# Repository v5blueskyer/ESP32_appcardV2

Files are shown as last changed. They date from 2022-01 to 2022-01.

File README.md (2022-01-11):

# appcardV2
基于乐鑫esp32的多功能应用卡片V2，天气时钟投屏等全都有，QQ技术群：801516857

原理图及PCB见立创开源社区：https://oshwhub.com/blueskyer/appcardv2

20220101更新，
 //我的更改说明：V1.2程序，修改了烧录方式，不再需要使用麻烦的arduino分区了，直接一键烧写。
烧写见附件说明

20211209更新，增加了闹钟固件，具体见附件里面txt

 //我的更改说明：V1.1程序

//1,增加了闹钟,在配网里面，配网完成后需要上电前按下按键选择闹钟打开模式才能使用,默认响1分钟,响铃的时候长按按键可关闭。

注意烧写bin文件前，必须用arduino刷个空程序以便将分区信息刷进去后才能操作刷bin程序，这点esp32和esp8266完全不一样。

一，    硬件部分
1，pcb板打板使用“Gerber_PCB_appcardV2.zip”，也可，直接打板即可。
板子厚度1.6mm，无其他要求，因为3d外壳是根据这个设计的

2，元器件采购
直接按照原理图或者pcb图。

蜂鸣器高度需要注意，3d外壳预留了1.5mm，实际最终
蜂鸣器高度不能超过5.5mm。

另外使用的是esp32 wrover，不是wroom，二者封装不同。

3，    其他硬件材料
（1）    屏幕

插接款-不带触屏，st7789

需要触屏的自己开发，电路和程序需要修改的

（2）    螺丝
螺丝使用4个m2*10或者8个m1*5的，担心滑丝的，尽量买m1的螺丝

4，3d打印外壳

文件有4个，但是类型有3个

appcard-Body是底壳
appcard-Body001是盖板
appcard-btn002和appcard-btn003对应不同长度的按键，前面一个安装后多出来1mm，后面一个多出来2mm

3d打印方式尽量选择光固化，因为那几个1mm螺丝孔要求精度高，其他打印方式可能不够好。

5，焊接和装配说明
  焊接和装配可看b站视频
  焊接需要注意的有
A，插件引脚需要剪掉和pcb持平
B，光敏电阻是需要多出来一点，刚好在开槽那里弯折一下，然后伸出来一部分
 
C，Typec固定的4个脚尽量往外移动一些，这样方便typec座子里面的卡子卡住typec数据线
D，pcb的挨在一起的B和G是用于短接用的，可以不焊接插针。
   6个排针那里不用串口的话可以不焊接，需要用只焊接4个（3V3，G，RX，TX）就行，不论是插针还是排母都需要弯折一下
不然高度太高了，根本安装不上外壳了

 6，5v的typec供电部分电源，尽量选择低电流的充电器，1a或者2a的，不要使用太大电流的。

更多内容参看附件里面的PDF文档，附件限制了文件大小，彩屏投屏助手太大我放到网盘了。

网盘链接：https://pan.baidu.com/share/init?surl=oSA9dAb9utCoeQdWQqr4jA

提取码：9527

高清视频请查看：https://www.bilibili.com/video/BV1wg411w77z/

欢迎点赞和收藏

<br>我的更改说明：V1.0程序
<br>移植SD2代码到esp32，引脚需改变，引脚和分辨率需改变，主要更改Arduino\libraries\TFT_eSPI\User_Setup.h以及主程序appcard.ino中窗口大小
<br>底部空区域增加b站粉丝数，增加用于显示b站字符的中文字体，底部增加b站图标
<br>增加NVS读取，esp32和8266的wifi用户名和密码保存区不一样，8266直接保存在flash区不用额外处理，esp32保存在NVS区需要手动调用
<br>修改配网模式，改为web配网，配网页面中可输入城市代码和b站uid
<br>城市名称字体不全，替换全量字体
<br>增加自动亮度控制
<br>增加开机动画，目前3张，需要其他图片自行修改后编译
<br>预留闹钟功能，后续添加代码
<br>修改串口功能，去掉了城市代码设置(因为配网中已经有了)，新增常用亮度设置（自动亮度关闭时），最低亮度设置（自动亮度打开时），英语单词本轮播时间设置(分钟)
<br>断电情况下，按下按钮不松开，然后插上TYPE-C数据线通电，上电后大概等待1秒，屏幕上会有提示，提示停留在哪一个步骤，松开按钮就会进入该步骤，重启后生效
<br>按键控制功能有：
<br>1,自动亮度打开与关闭
<br>2,配网模式
<br>3,开机动画关闭
<br>4,开机动画设置为图片1（默认）
<br>5,开机动画设置为图片2
<br>6,开机动画设置为图片3
<br>7,底部动画设置为图片1（默认）
<br>8,底部动画设置为图片2
<br>9,页面选择1天气时钟（默认）
<br>10,页面选择2全屏数字时钟
<br>11,页面选择3圆盘时钟
<br>12,页面选择4投屏助手
<br>13,页面选择5英语单词本
<br>14,页面选择6喝水小助手
<br>15,页面选择7游戏flappy bird
<br>16,页面选择8系统信息
<br>17,页面选择9关于
<br>增加全屏数字时钟界面，按下按键可立即同步ntp时间
<br>增加圆盘时钟界面，按下按键可立即同步ntp时间
<br>增加投屏功能页面，需上位机配合
<br>增加英语单词本功能，支持轮播时间设置，按下按键可立即换单词和同步ntp时间,默认7990个单词。
<br>增加喝水小助手功能，默认8杯水，按一次增加一次，提示不同内容和显示进度，掉电不丢失，每天夜间1点10分清0重新计数。超过24次后，重启会清零。
<br>增加游戏flappy bird，按键操作，最高分保存记录掉电不丢失

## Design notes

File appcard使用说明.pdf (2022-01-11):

Appcard 使用说明

# 一， 硬件部分

1， pcb 板打板使用“Gerber_PCB_appcardV2.zip”，直接打板即可。 板子厚度 1.6mm，无其他要求，因为 3d 外壳是根据这个设计的

2， 元器件采购
直接按照原理图或者 pcb 图。
立创开源地址： https://oshwhub.com/blueskyer/appcardv2

蜂鸣器高度需要注意，3d 外壳预留了 1.5mm，实际最终 蜂鸣器高度不能超过 5.5mm。

另外使用的是 esp32 wrover，不是 wroom，二者封装不同。

3， 其他硬件材料
（1） 屏幕
https://item.taobao.com/item.htm?spm=a1z09.2.0.0.54c02e8dASAeNj&id=605985020631&_u=rpab1dmd2dc

插接款-不带触屏，23 元

需要触屏的自己开发，电路和程序需要修改的

（2） 螺丝
螺丝使用 4 个 m2*10 或者 8 个 m1*5 的，担心滑丝的，尽量买 m1 的螺丝

4，3d 打印外壳

文件有 4 个，但是类型有 3 个

appcard-Body 是底壳
appcard-Body001 是盖板
appcard-btn002 和 appcard-btn003 对应不同长度的按键，前面一个安装后多出来 1mm，后面一个多出来 2mm

3d 打印方式尽量选择光固化，因为那几个 1mm 螺丝孔要求精度高，其他打印方式可能不够好。

5，焊接和装配说明
焊接和装配可看 b 站视频
焊接需要注意的有
A，插件引脚需要剪掉和 pcb 持平
B，光敏电阻是需要多出来一点，刚好在开槽那里弯折一下，然后伸出来一部分

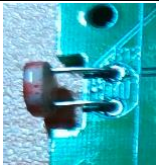
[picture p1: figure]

C， Typec 固定的 4 个脚尽量往外移动一些，这样方便 typec 座子里面的卡子卡住 typec 数据线
D，第一个框的 B 和 G 是用于短接用的，可以不焊接插针。 第二个框的，不用串口的话可以不焊接，需要用只焊接画框的 4 个就行，不论是插针还是排母都需要弯折一下 不然高度太高了，根本安装不上外壳了，类似下图处理。

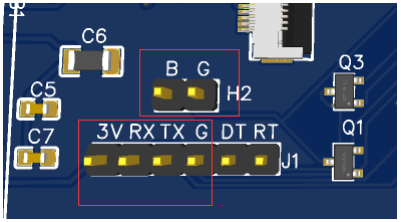
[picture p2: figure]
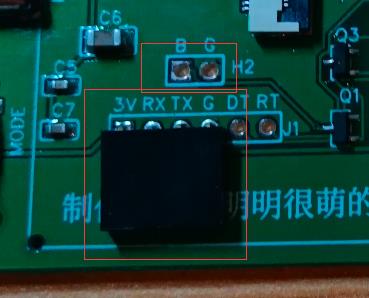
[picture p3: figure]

6，5v 的 typec 供电部分电源，尽量选择低电流的充电器，1a 或者 2a 的，不要使用太大电流的。

# 二， 软件部分

## 1， 程序烧录方法

板子自带 ch340c 下载器，同时预留了 usb 转 ttl 串口，可以上电前短接 boot 和 gnd，再接 usb 转 ttl 即可

图上最上面 2 个短接，下面 4 个用于 usb 转 ttl。

（1）所需软件，arduino，flash_download_tool，分区表相关文件(见分区表文件夹)

（2）Arduino 需要配置好开发板类型，开发板管理里面能够显示 esp32 wrover，教程这里就不罗列了，可以自行百 度。

（3）接着替换分区表文件，因为本程序是 3.5M，默认分区表最大只有 3M

涉及 2 个文件，操作前最好备份一下你自己的文件。

（4）替换 boards.txt，这个定义的是板子类型及指向的分区表文件名 C:\Users\你的用户名\AppData\Local\Arduino15\packages\esp32\hardware\esp32\1.0.6

（5）新增 big_app.csv，这个定义分区信息，不要去编辑，可以查看，csv 容易乱码保存容易出问题 C:\Users\你的用户名\AppData\Local\Arduino15\packages\esp32\hardware\esp32\1.0.6\tools\partitions

看不到隐藏文件夹请打开操作系统对应设置，自行百度，这里就不说了。

(6) arduino 新建一个空白程序，然后选择分区表，烧写进去，这一步是位了将分区信息写进去

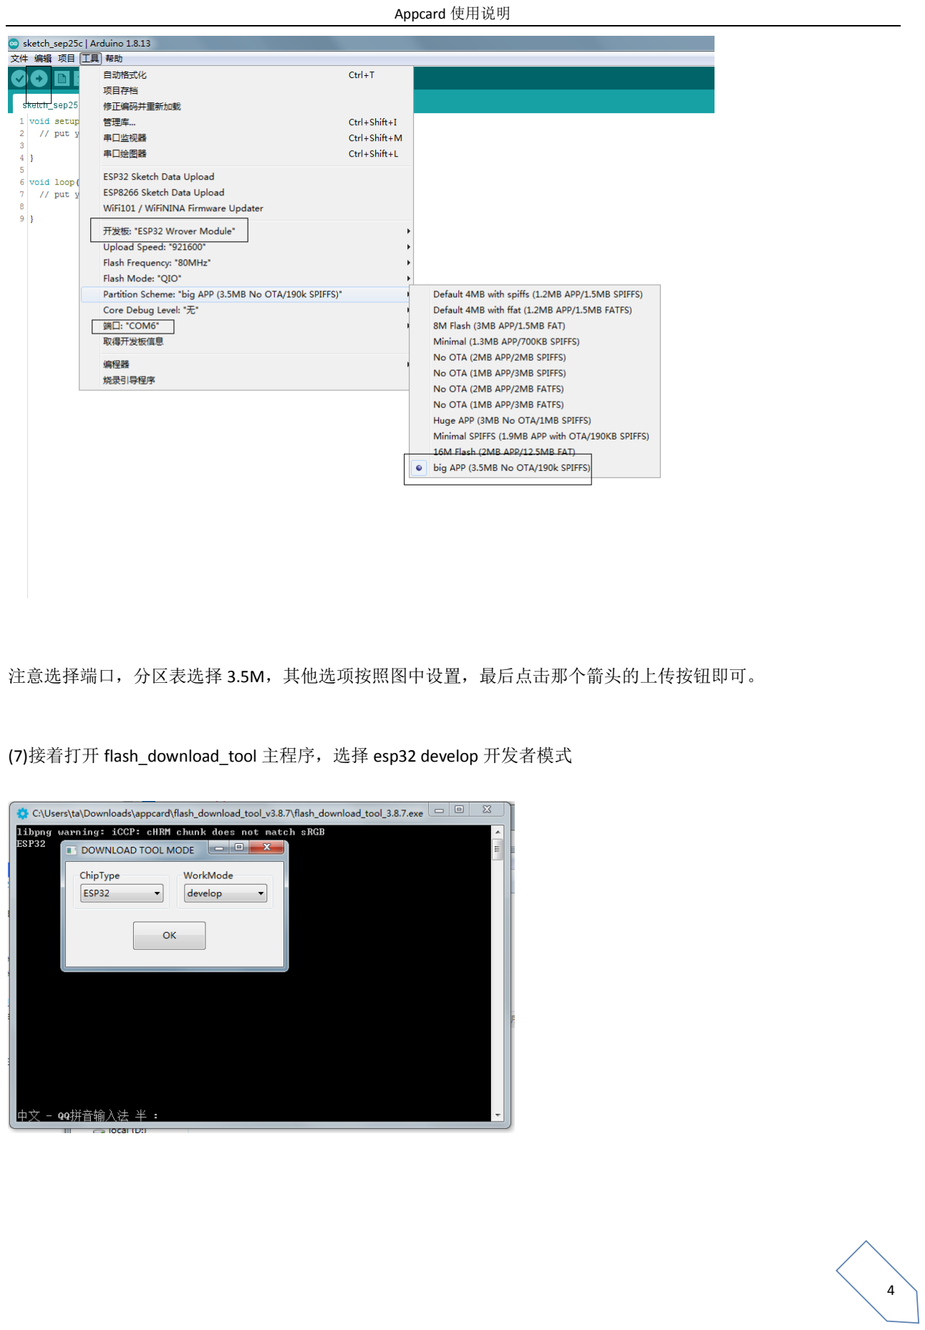
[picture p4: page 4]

注意选择端口，分区表选择 3.5M，其他选项按照图中设置，最后点击那个箭头的上传按钮即可。

(7)接着打开 flash_download_tool 主程序，选择 esp32 develop 开发者模式

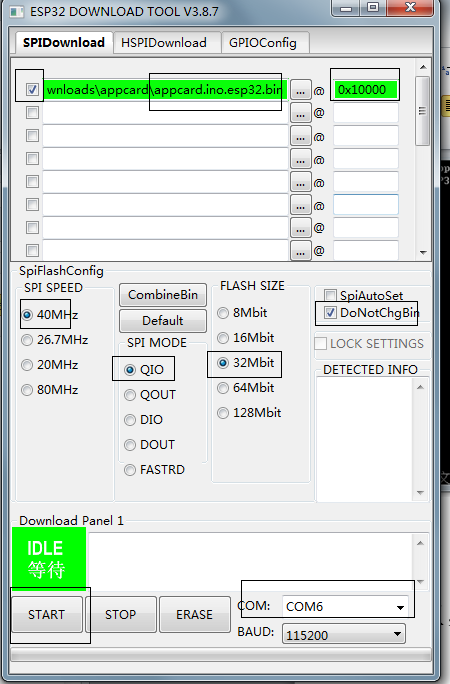
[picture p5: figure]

先选择固件 bin 文件，勾选，然后填入地址 0x10000，除了 com 口外其他按照图中设置即可，com 口根据你对应上 的，一般操作系统设备管理器端口里面可以看到

点击 start 就开始刷写了，刷写后需要拔电源重新插上屏幕才有显示。

到这里基本刷写就结束了，接下来是软件使用部分了。

## 2， 软件使用教程

（1） 先罗列我修改了哪些功能吧，后面也基本围绕这个。

//我的更改说明：V1.0 程序
//移植 SD2 代码到 esp32，引脚需改变，引脚和分辨率需改变，主要更改 Arduino\libraries\TFT_eSPI\User_Setup.h 以

及主程序 appcard.ino 中窗口大小
//底部空区域增加 b 站粉丝数，增加用于显示 b 站字符的中文字体，底部增加 b 站图标
//增加 NVS 读取，esp32 和 8266 的 wifi 用户名和密码保存区不一样，8266 直接保存在 flash 区不用额外处理，esp32 保存在 NVS 区需要手动调用
//修改配网模式，改为 web 配网，配网页面中可输入城市代码和 b 站 uid
//城市名称字体不全，替换全量字体
//增加自动亮度控制
//增加开机动画，目前 3 张，需要其他图片自行修改后编译
//预留闹钟功能，后续添加代码
//修改串口功能，去掉了城市代码设置(因为配网中已经有了)，新增常用亮度设置（自动亮度关闭时），最低亮度设 置（自动亮度打开时），英语单词本轮播时间设置(分钟)
//断电情况下，按下按钮不松开，然后插上 TYPE-C 数据线通电，上电后大概等待 1 秒，屏幕上会有提示，提示停留 在哪一个步骤，松开按钮就会进入该步骤，重启后生效
//按键控制功能有：
//1,自动亮度打开与关闭
//2,配网模式
//3,开机动画关闭
//4,开机动画设置为图片 1（默认）
//5,开机动画设置为图片 2
//6,开机动画设置为图片 3
//7,底部动画设置为图片 1（默认）
//8,底部动画设置为图片 2
//9,页面选择 1 天气时钟（默认）
//10,页面选择 2 全屏数字时钟
//11,页面选择 3 圆盘时钟
//12,页面选择 4 投屏助手
//13,页面选择 5 英语单词本
//14,页面选择 6 喝水小助手
//15,页面选择 7 游戏 flappy bird
//16,页面选择 8 系统信息
//17,页面选择 9 关于
//增加全屏数字时钟界面，按下按键可立即同步 ntp 时间
//增加圆盘时钟界面，按下按键可立即同步 ntp 时间
//增加投屏功能页面，需上位机配合
//增加英语单词本功能，支持轮播时间设置，按下按键可立即换单词和同步 ntp 时间,默认 7990 个单词。 //增加喝水小助手功能，默认 8 杯水，按一次增加一次，提示不同内容和显示进度，掉电不丢失，每天夜间 1 点 10 分清 0 重新计数。超过 24 次后，重启会清零。
//增加游戏 flappy bird，按键操作，最高分保存记录掉电不丢失
(2) 首次使用开机后会显示配网信息页面，用手机或者电脑找到名为“appcard”这个无线网进行连接，默认无密码的， 接着会弹一个浏览器弹窗，如果没弹窗则需要你打开浏览器手动输入”192.168.4.1”。

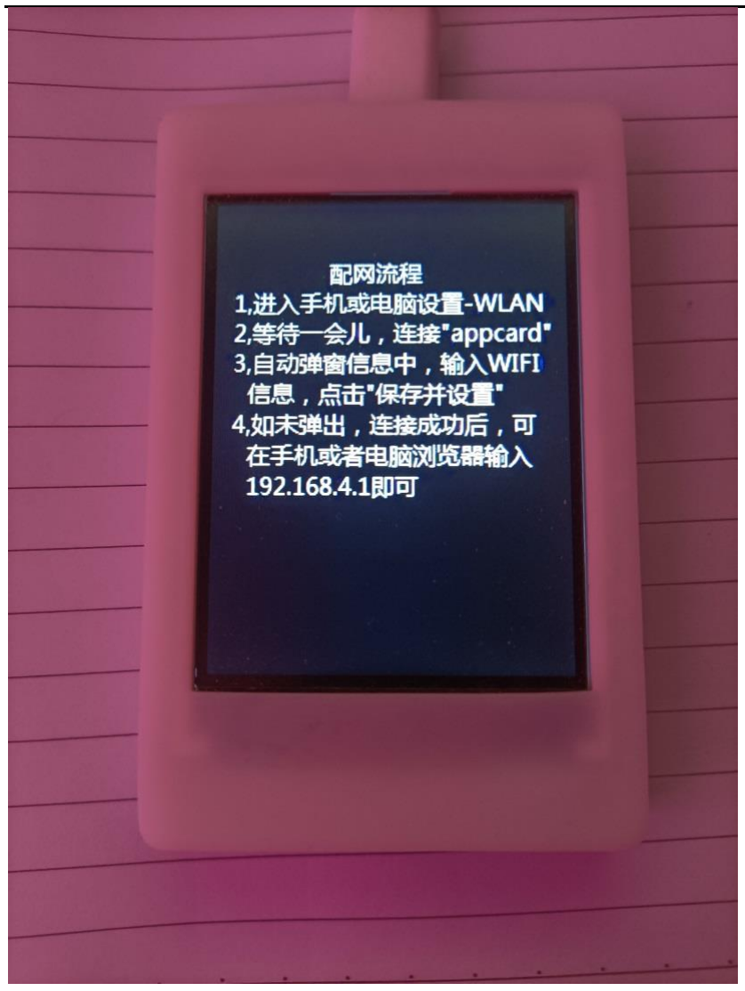
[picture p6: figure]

(3) 接着填入 wifi 网络名和密码即可，城市 id 和 b 站 id 也可以不填。 城市 id 是自动获取的，但有时候获取不准，所以建议还是填一下。 B 站 id 是默认 up 的 id，如果需要你自己的可以填一下。
城市 id，可以在 citycode 文件里面的 js 获取，本稳当结尾也会加的。

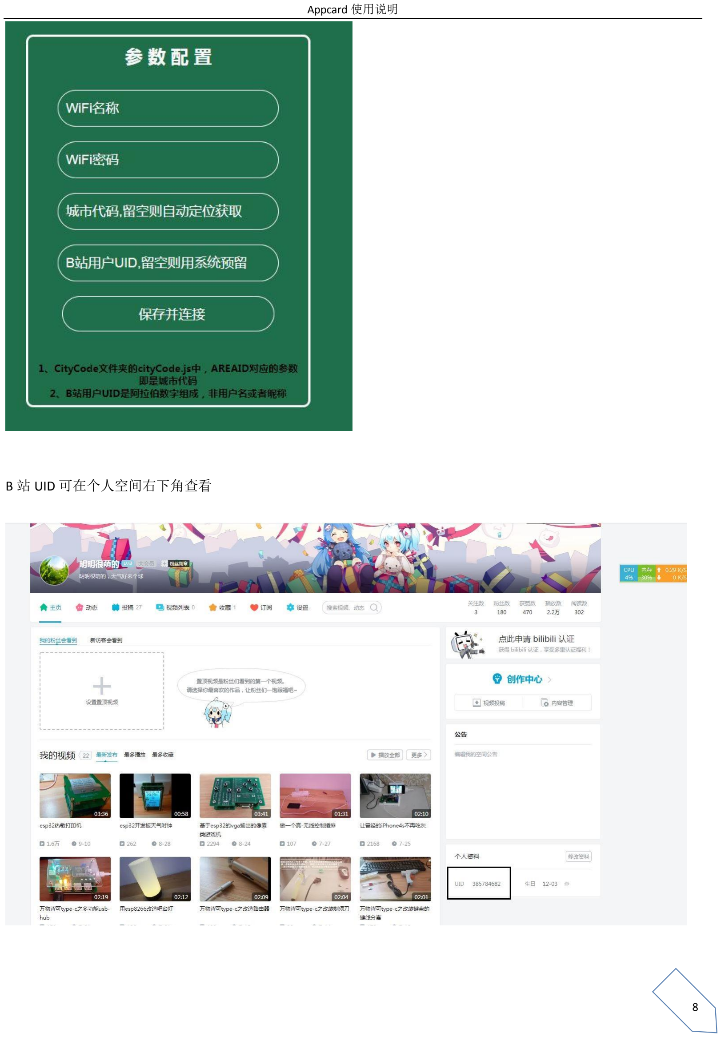
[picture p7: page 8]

B 站 UID 可在个人空间右下角查看

（4）默认首次进入天气时钟界面，进入时界面元素较多，有些卡，可以等待一下即可。 如果界面元素不全或者时间不对，可以重新上电进入即可，后续其他页面的时间不对也是如此操作。

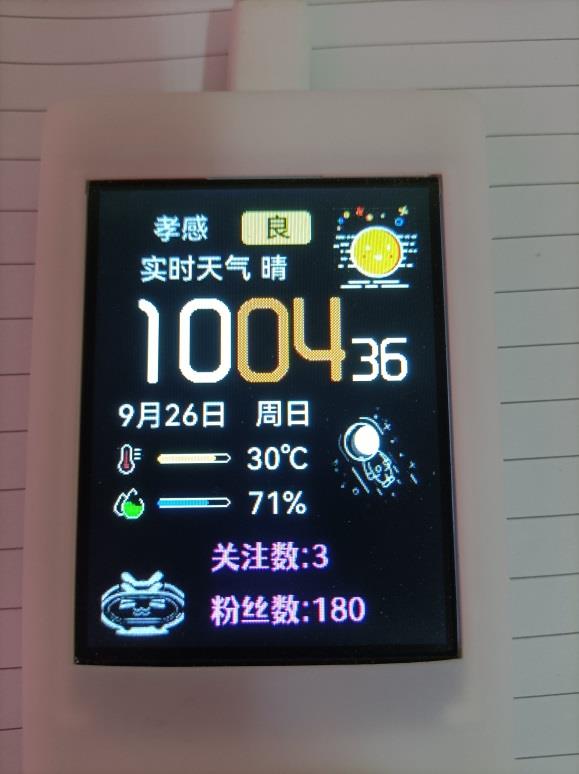
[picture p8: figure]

按下按键可以立即刷新时间和粉丝数

基本上到此，就可以正常使用了，后续讲其他功能。

（5）如果要调整显示页面和进行一些设置，可以用串口工具或者按键。

（6）先说下串口工具，不用网上下载各种串口软件，直接使用 arduino 的即可 打开 arduino 串口监视器，注意端口要正确

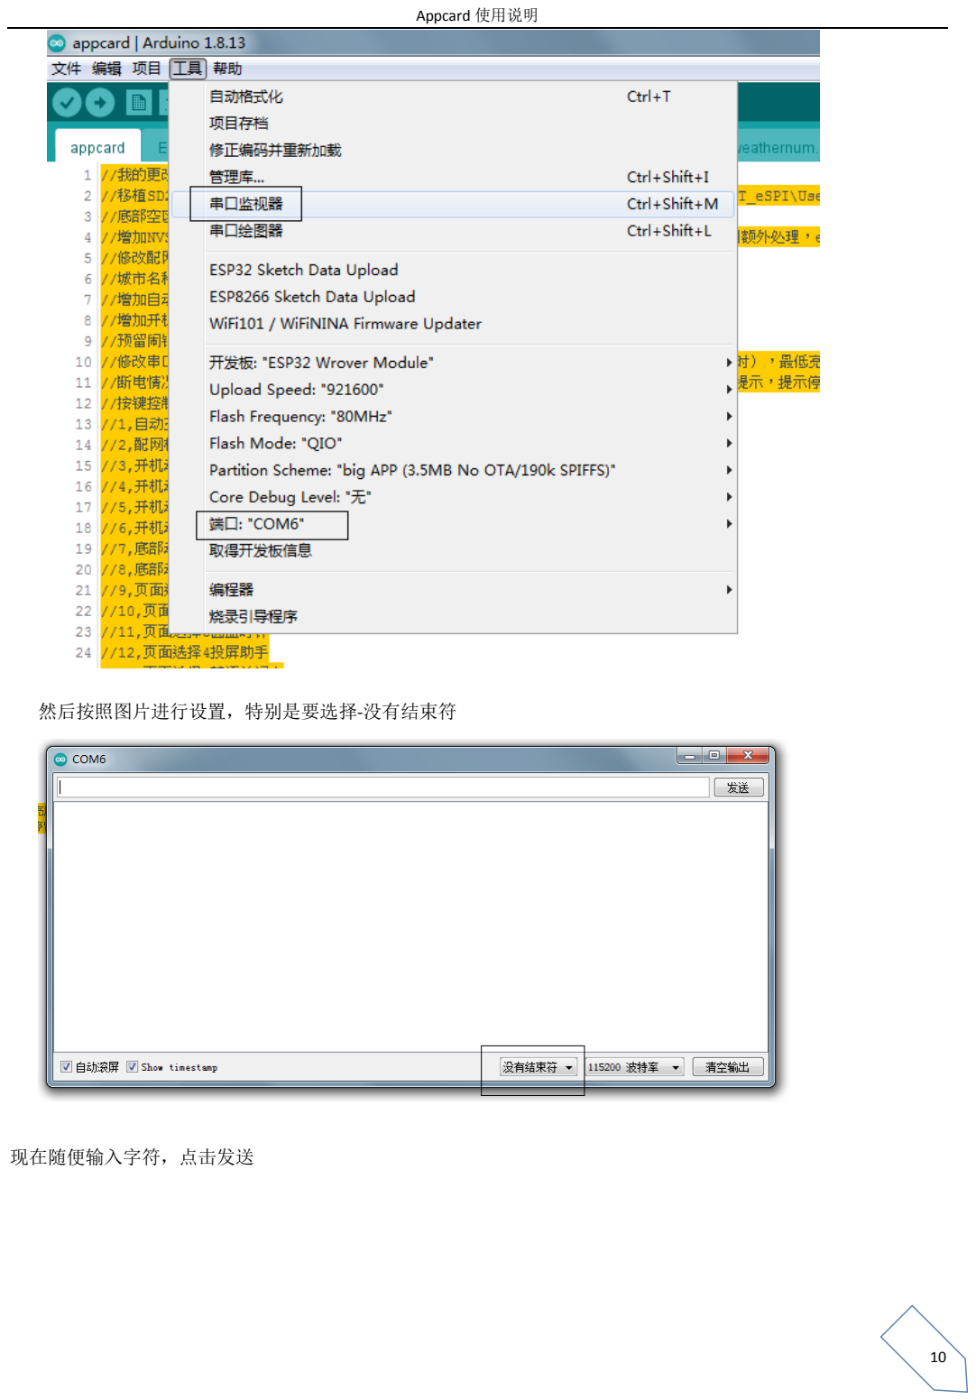
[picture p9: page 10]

然后按照图片进行设置，特别是要选择-没有结束符

现在随便输入字符，点击发送

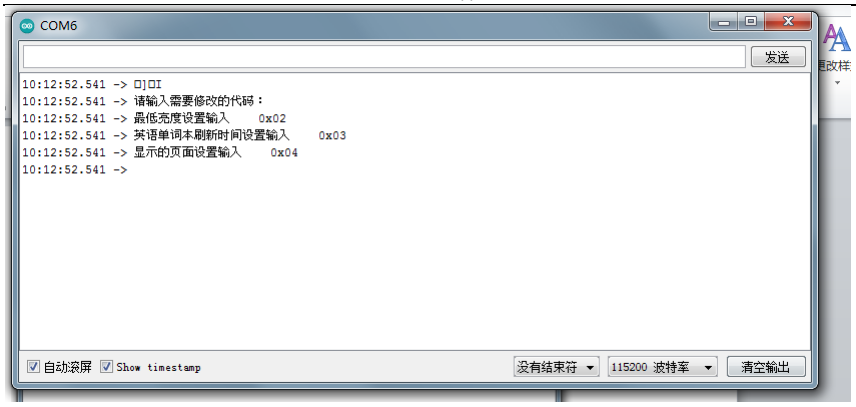
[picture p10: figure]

默认有 4 个设置
0x01 常用亮度设置（自动亮度关闭有效）
0x02 最低亮度设置（自动亮度打开有效）
0x03 英语单词本刷新时间设置
0x04 显示的页面设置

Appcard 使用了光敏电阻，默认自动亮度是打开的，所以这里看不到 0x01,关闭后就能看到了，0x02 也同理，自动亮 度打开才有效

常用亮度是用于自动亮度关闭时，屏幕一直长亮使用的亮度，默认 150，可根据自定义调整 最低亮度是用于自动亮度打开时，完全黑暗环境下的亮度，默认 30，因为黑暗环境如果屏幕太暗较远看的话就有些 看不清了，根据需要调整。，

0x03 是英语单词本页面用的，目前默认 1 分钟，如果想慢点就可以设置更长时间

0x04 是页面功能，想要哪个页面就输入哪个页面，目前有 9 个页面，输入数字 1-9

接下来是演示
比如调整最低亮度
输入 0x02，提示输入值

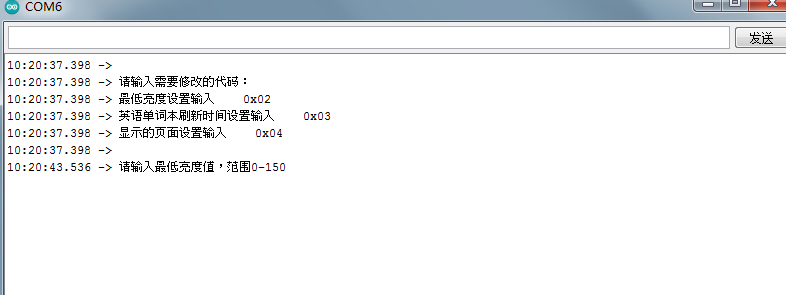
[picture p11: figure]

输入 30 后，立即生效。

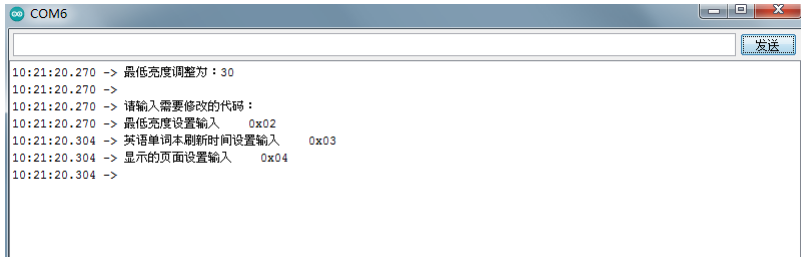
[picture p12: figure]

0x03 和 0x04 的设置，则需要重启生效

(7)接下来讲页面不同的功能

页面 1，天气时钟
显示各种天气信息，温湿度，时间，粉丝数等，各种信息会每隔 5 分钟刷新一次，自动 NTP 校准时间，按下按键可 立即刷新粉丝数和时间

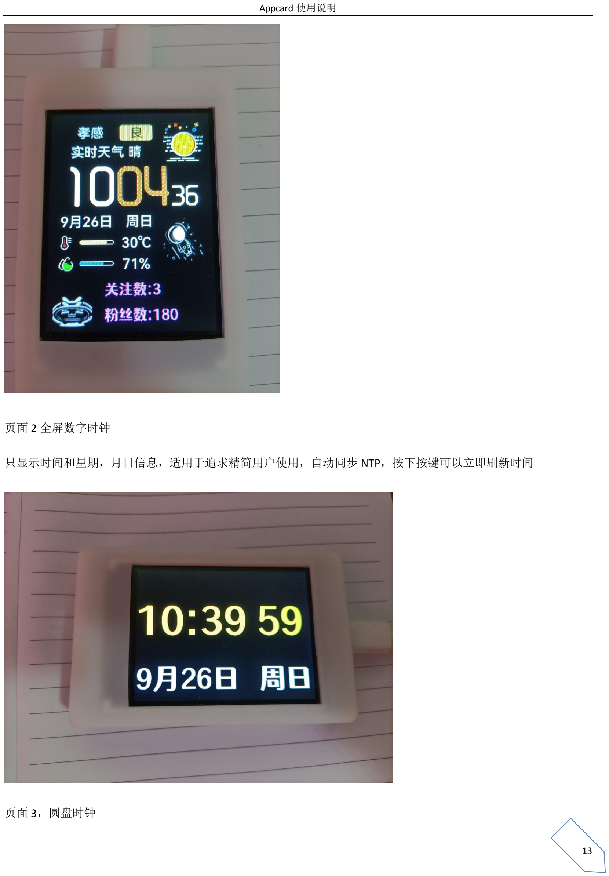
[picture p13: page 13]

页面 2 全屏数字时钟

只显示时间和星期，月日信息，适用于追求精简用户使用，自动同步 NTP，按下按键可以立即刷新时间

页面 3，圆盘时钟

自动显示上午（am）和下午（pm），自动同步 ntp 时间，按下按键立即刷新。

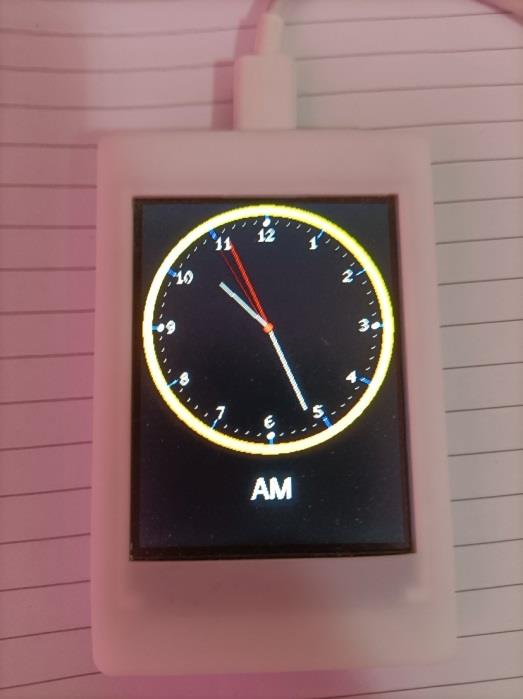
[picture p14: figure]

页面 4，投屏助手，需要上位机配合。
可以将 pc 端信息投屏过来，可以看图片看文档，还能安装一些监控工具，投屏助手工具将监控界面选择就能作为 监控显示器了。

页面进入后会是这样，显示 ip 和端口，等待上位机通讯

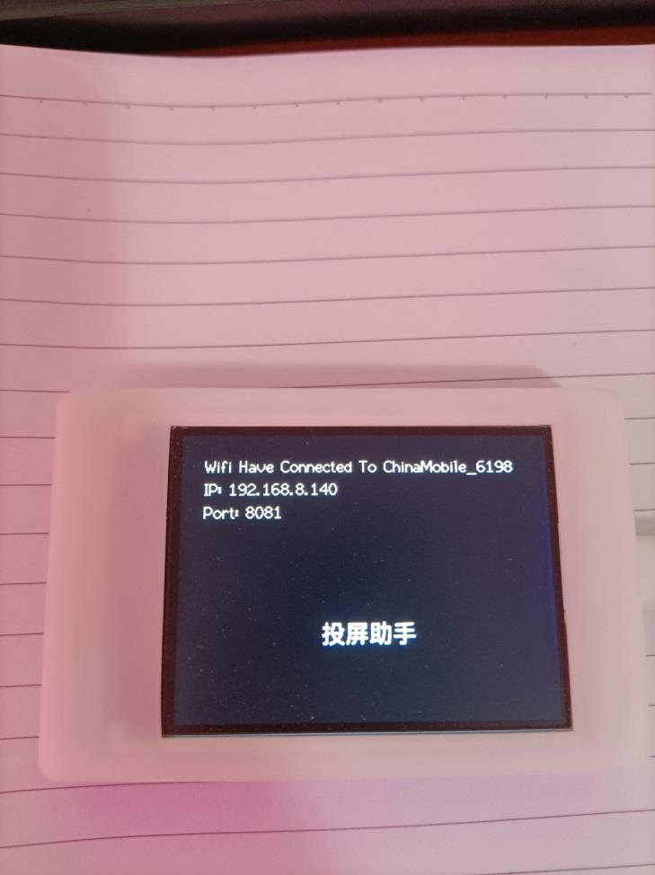
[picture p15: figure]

接着打开上位机程序，也就是“彩屏投屏助手-mini-v1.3.exe”。

点击设置-连接设置，填入 ip 及端口，appcard 屏幕上显示的就是

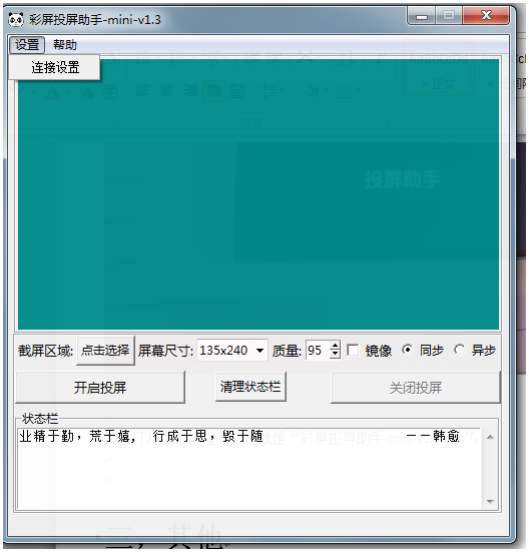
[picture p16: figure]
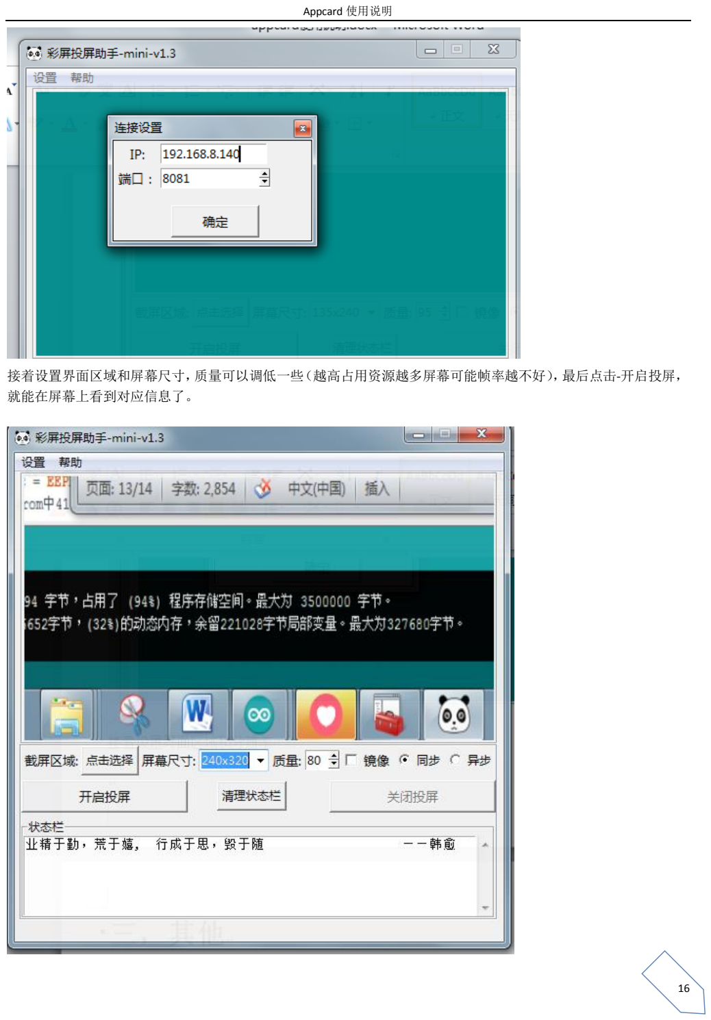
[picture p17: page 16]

接着设置界面区域和屏幕尺寸，质量可以调低一些（越高占用资源越多屏幕可能帧率越不好），最后点击-开启投屏， 就能在屏幕上看到对应信息了。

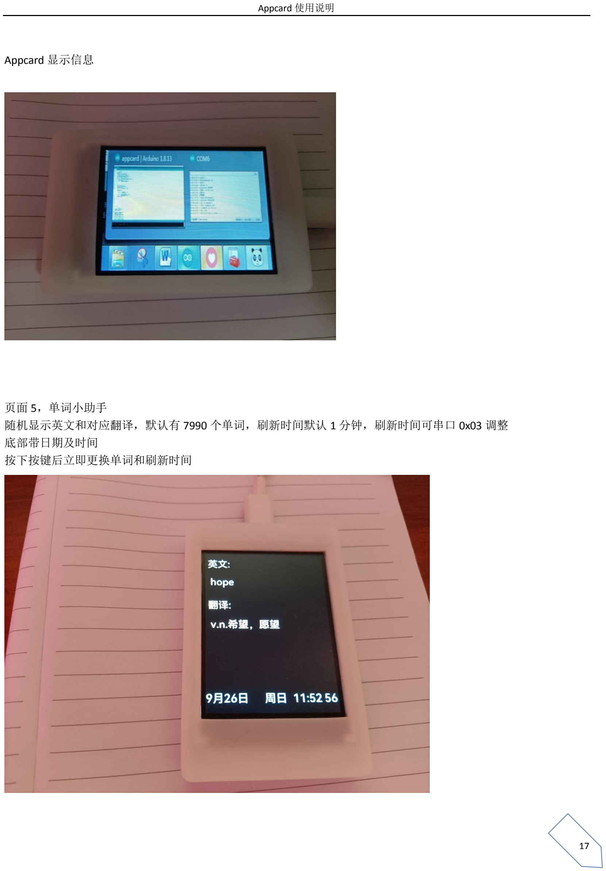
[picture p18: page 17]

Appcard 显示信息

页面 5，单词小助手
随机显示英文和对应翻译，默认有 7990 个单词，刷新时间默认 1 分钟，刷新时间可串口 0x03 调整 底部带日期及时间
按下按键后立即更换单词和刷新时间

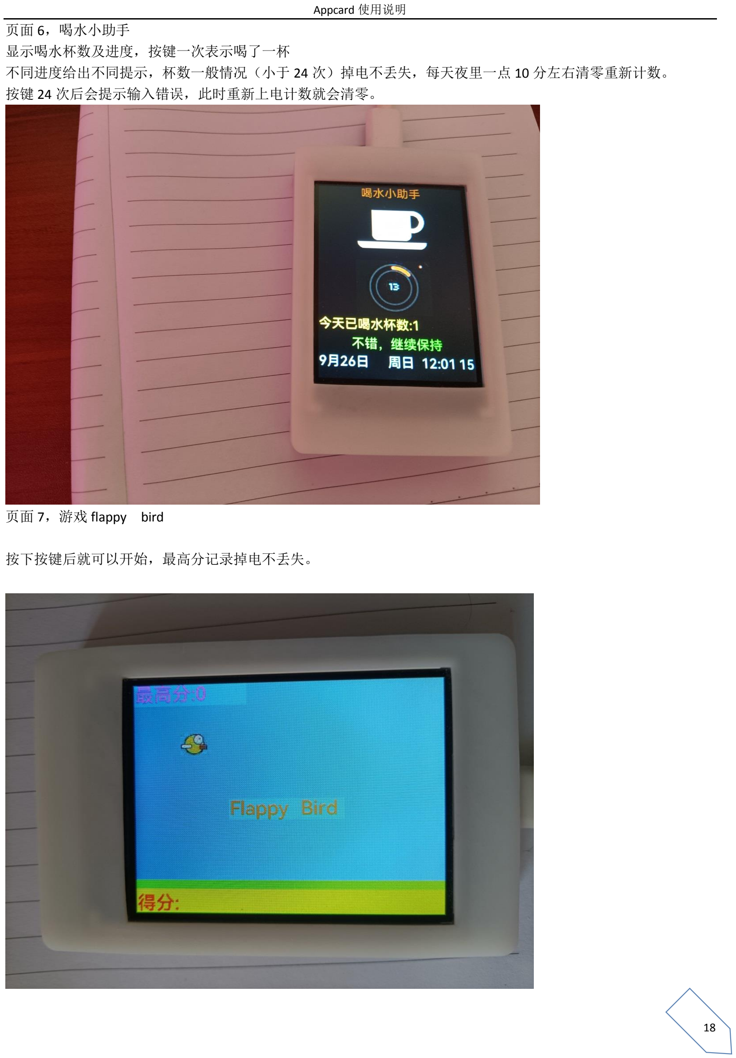
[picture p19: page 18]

页面 6，喝水小助手
显示喝水杯数及进度，按键一次表示喝了一杯
不同进度给出不同提示，杯数一般情况（小于 24 次）掉电不丢失，每天夜里一点 10 分左右清零重新计数。 按键 24 次后会提示输入错误，此时重新上电计数就会清零。

页面 7，游戏 flappy bird

按下按键后就可以开始，最高分记录掉电不丢失。

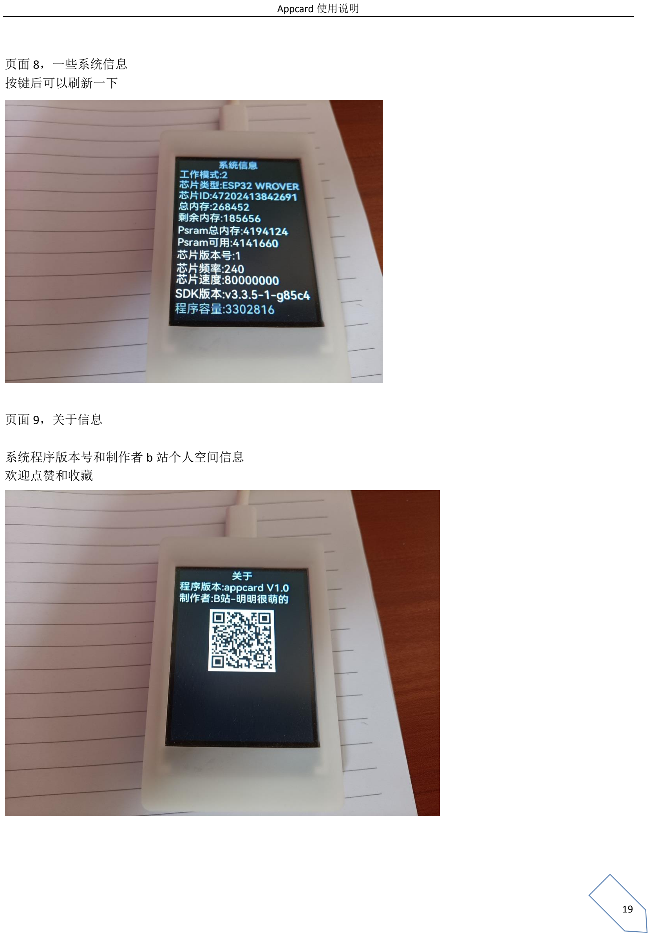
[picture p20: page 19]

页面 8，一些系统信息
按键后可以刷新一下

页面 9，关于信息

系统程序版本号和制作者 b 站个人空间信息
欢迎点赞和收藏

（8）最后是按键部分

断电情况下，按下按钮不松开，然后插上 TYPE-C 数据线通电，上电后大概等待 1 秒，屏幕上会有提示，提示停留在 哪一个步骤，松开按钮就会进入该步骤，重启后生效

主要功能有自动亮度开关，开机动画开关与更换，配网功能，底部 b 站图标更换，闹钟开关，跳转不同页面。

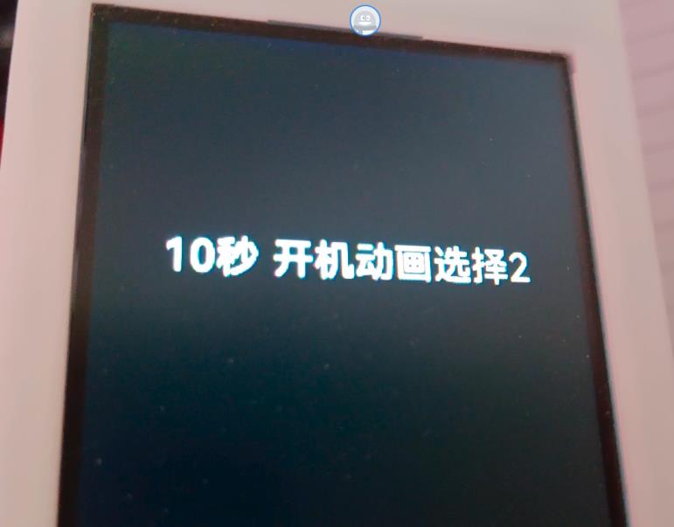
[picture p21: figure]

# 三， 其他

制作者：B 站 明明很萌的

二维码：

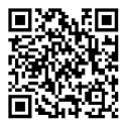
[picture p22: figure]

个人空间：https://space.bilibili.com/385784682

所有涉及硬件及软件部分，仅用于 DIY 爱好者技术分享，请不要用于商用，如需商用请联系作者。

限于时间和其他原因，现在只做到了 V1.0 程序版本
待修复和后续添加部分
1，闹钟部分
2，SOS 功能

3，游戏 flappy bird 界面无法串口通信，可能进程占用了，需要使用按键进行界面切换。 4，其他按键游戏

可后续硬件扩展部分
1， 增加 sd 卡
2， 增加贴片 led
3， 增加传感器

参考部分来源于网络：

1， 天气时钟界面源代码
原来的是 8266，改成了 esp32 适配
https://www.bilibili.com/video/BV1V64y1e72M 2， 硬件及按键切换功能，配网功能：
https://www.bilibili.com/video/BV1hy4y1W7NL 3， 投屏功能
https://www.bilibili.com/video/BV18g411T7js
4， Flappy bird

原始显示屏驱动不包含 7789 型号，所以基本上代码改了一大半以上，使用的 TFT_eSPI 驱动代替。

https://www.bilibili.com/video/BV18441157o6

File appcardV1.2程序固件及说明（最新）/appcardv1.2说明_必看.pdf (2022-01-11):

我的更改说明：V1.2 程序
1,更新了烧录方式，不再使用麻烦的 arduino 手动分区，实现一键烧写。

烧录方式有变更，不再使用之前的 arduino 分区方式，直接使用 flash_download_tool 烧写。

一，打开 flash_download_tool，点击 3 个…选择正确的 bin 文件位置（不要手动输入），然后 勾选，@后面填烧写地址 0x00000，SPI SPEED(SPI 速度)选择 40MHz，SPI MODE（SPI 模式） 选择QIO，FLASH SIZE（内存大小）选择32Mbit(换算成M，需要除以8，也就是4M)，DoNotChgbin （不改变 bin 文件）勾选，端口 COM 选择正确的端口（windows 设备管理器-端口里面，有 ch340 的那个），BAUD（烧写速率）选择 921600, 然后点击 “START”开始烧写。

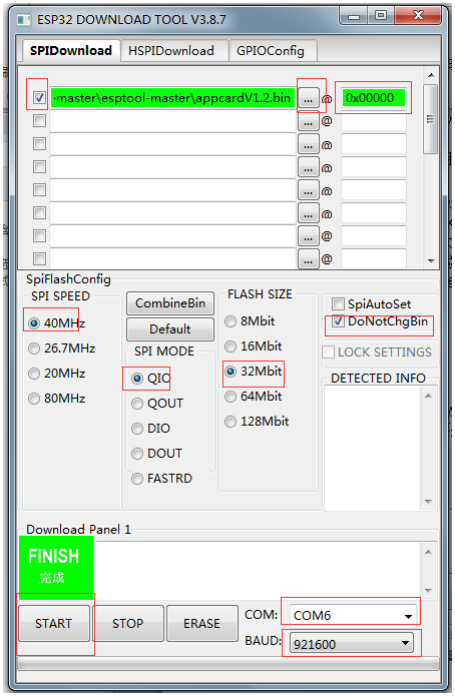
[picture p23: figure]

二，烧写完成后，会显示“FINISH 完成”，需要拔线或者手动关掉开关重启

三，上述是首次使用 esp32 wrover 芯片教程，如果你之前刷过其他程序，可能调用了 eeprom 区，为防止数据异常，需要先点击“ERASE”进行清除。清除后再进行步骤一和二的操作。

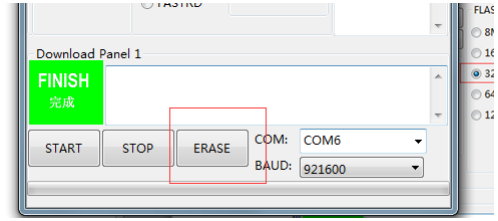
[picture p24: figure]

至此，appcardV2 版本停止维护（硬件为 appcardv2，软件为 appcardv1.2），不再有后续更新。

新项目见 appcardV3，广场地址：https://oshwhub.com/blueskyer/appcardv3

QQ 技术群：801516857

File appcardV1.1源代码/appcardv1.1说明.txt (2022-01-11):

 //我的更改说明：V1.1程序
//1,增加了闹钟,在配网里面，配网完成后需要上电前按下按键选择闹钟打开模式才能使用,默认响1分钟,响铃的时候长按按键可关闭。

注意烧写bin文件前，必须用arduino刷个空程序以便将分区信息刷进去后才能操作刷bin程序，这点esp32和esp8266完全不一样。

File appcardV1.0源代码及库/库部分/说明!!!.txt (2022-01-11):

因为涉及的库太多以免遗漏，所以一次全打包了
将解压后的文件夹放置arduino的libraries目录，否则会编译失败，替换前备份一下你自己的库文件

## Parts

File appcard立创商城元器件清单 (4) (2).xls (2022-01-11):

购买类型 | 商品编号 | 物料编码 | 商品分类 | 名称 | 商品型号 | 品牌 | 封装规格 | 单个毛重 | 购买数量 | 商品单价 | 金额
常规 | C393939 |  | USB连接器 | type-c母座16pin 快充闪充usb3.0沉板母座连接器 | TYPE-C16PIN | SHOU HAN(首韩) | SMD | 0.000839 | 5 | ￥0.664043 | ￥3.32
常规 | C424705 |  | 线性稳压器(LDO) | XC6210B332MR | XC6210B332MR | TOREX(特瑞仕) | SOT-25 | 0.000121 | 1 | ￥1.6430 | ￥1.64
常规 | C84681 |  | USB芯片 | CH340C | CH340C | WCH(南京沁恒) | SOP-16_150mil | 0.000280 | 1 | ￥3.26 | ￥3.26
常规 | C503590 |  | WiFi模块 | ESP32-WROVER | ESP32-WROVER | ESPRESSIF 乐鑫 | Module | 0.003120 | 1 | ￥28.79 | ￥28.79
常规 | C881327 |  | 贴片电阻 | 220Ω ±1% | CR0603F220RP05Z | EVER OHMS(天二科技) | 0603 | 0.000023 | 100 | ￥0.010391 | ￥1.04
常规 | C125627 |  | 光敏电阻 | GL5528 | GL5528 | 森霸 | 插件 | 0.000222 | 10 | ￥0.203166 | ￥2.03
常规 | C177288 |  | 贴片电阻 | 1Ω ±5% | RCT031RJLF | HKR(香港电阻) | 0603 | 0.000024 | 100 | ￥0.012103 | ￥1.21
常规 | C25804 |  | 贴片电阻 | 10kΩ ±1% | 0603WAF1002T5E | UNI-ROYAL(厚声) | 0603 | 0.000023 | 100 | ￥0.006552 | ￥0.66
常规 | C364312 |  | 三极管(BJT) | S8050-J3Y | S8050-J3Y | MDD | SOT-23 | 0.000032 | 50 | ￥0.068967 | ￥3.45
常规 | C318936 |  | 轻触开关 | 轻触开关 7*3.45*3.5侧按固定柱 260g 白色按钮 | TS-1101VS-C-A-A | XKB Connectivity(中国星坤) | SMD | 0.000127 | 5 | ￥0.415712 | ￥2.08
常规 | C124375 |  | 排针 | 排针 1*2P 2.54mm 直插 | B-2100S02P-A110 | Ckmtw(灿科盟) | Through Hole,P=2.54mm | 0.000109 | 20 | ￥0.104326 | ￥2.09
常规 | C512918 |  | FFC/FPC连接器 | FFC/FPC 0.5mm间距 翻盖式 下接 18P | F0502-B-18-20T-R | XFCN(台湾兴飞) | P=0.5mm | 0.000452 | 5 | ￥0.539808 | ￥2.70
常规 | C1592 |  | 贴片电容(MLCC) | 1uF ±10% 16V | CL10A105KO8NNNC | SAMSUNG(三星) | 0603 | 0.000035 | 50 | ￥0.020295 | ￥1.01
常规 | C412630 |  | 贴片电容(MLCC) | 22uF ±10% 10V | LMK316ABJ226KL-T | TAIYO YUDEN(太诱) | 1206 | 0.000078 | 10 | ￥0.321957 | ￥3.22
常规 | C1591 |  | 贴片电容(MLCC) | 100nF ±10% 50V | CL10B104KB8NNNC | SAMSUNG(三星) | 0603 | 0.000035 | 100 | ￥0.016560 | ￥1.66
常规 | C252932 |  | 蜂鸣器 | GMD0942YB-3V2700 | GMD0942YB-3V2700 | INGHAi(赢海) | 插件 | 0.001000 | 1 | ￥3.38 | ￥3.38
编号C512918的FPC可以不买，买屏幕的时候店家会送2个 不需要usb转ttl的话，可以不用买排针也不用焊接排针（编号C124375），直接焊接ch340c即可

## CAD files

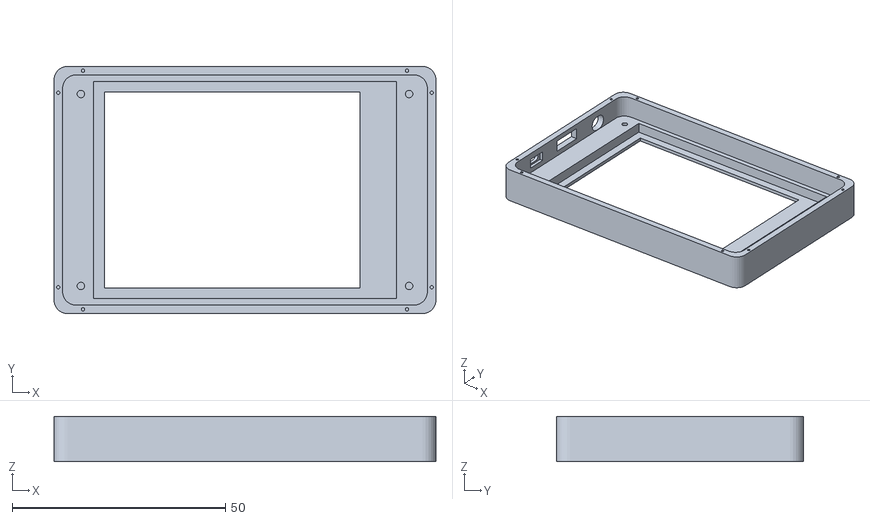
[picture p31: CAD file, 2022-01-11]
3d外壳/appcard-Body.stl
89.6 x 58.0 x 10.6

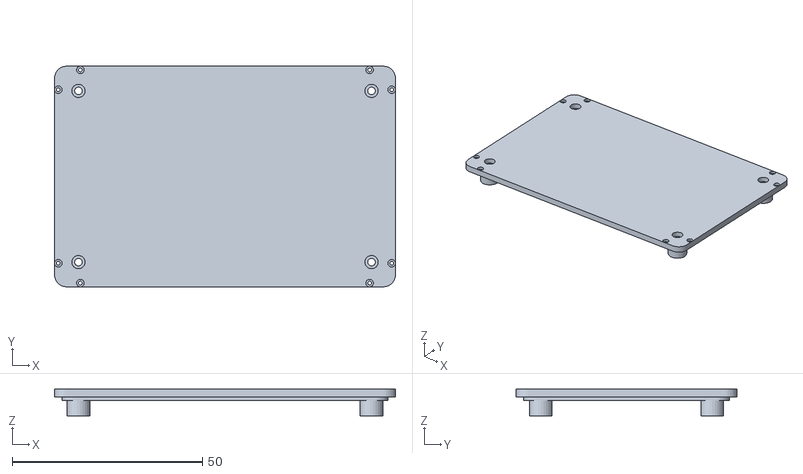
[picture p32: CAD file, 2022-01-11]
3d外壳/appcard-Body001.stl
89.6 x 58.0 x 7.00

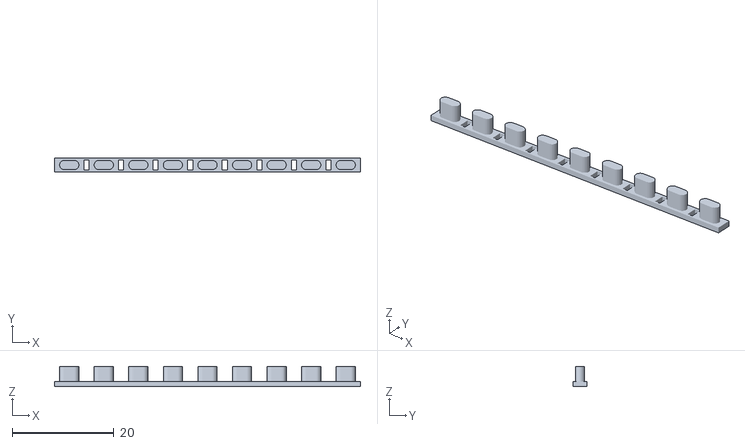
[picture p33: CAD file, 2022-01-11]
3d外壳/appcard-btn003.stl
60.2 x 2.80 x 4.00

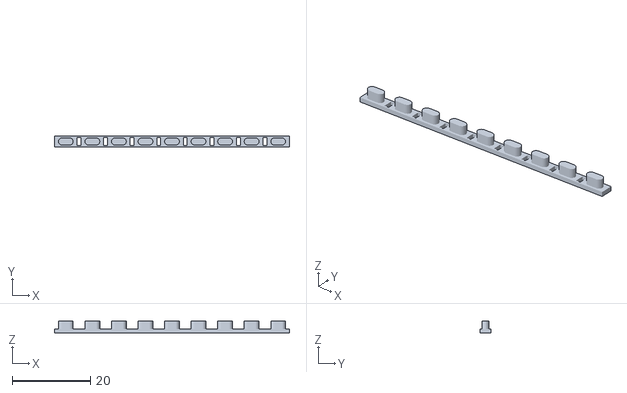
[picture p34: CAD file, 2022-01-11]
3d外壳/appcard-btn002.stl
60.2 x 2.80 x 3.00

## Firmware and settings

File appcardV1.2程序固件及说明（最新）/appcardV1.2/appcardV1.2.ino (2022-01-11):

//我的更改说明：V1.0程序
//移植SD2代码到esp32，引脚需改变，引脚和分辨率需改变，主要更改Arduino\libraries\TFT_eSPI\User_Setup.h以及主程序appcard.in中窗口大小
//底部空区域增加b站粉丝数，增加用于显示b站字符的中文字体，底部增加b站图标
//增加NVS读取，esp32和8266的wifi用户名和密码保存区不一样，8266直接保存在flash区不用额外处理，esp32保存在NVS区需要手动调用
//修改配网模式，改为web配网，配网页面中可输入城市代码和b站uid
//城市名称字体不全，替换全量字体
//增加自动亮度控制
//增加开机动画，目前3张，需要其他图片自行修改后编译
//预留闹钟功能，后续添加代码
//修改串口功能，去掉了城市代码设置(因为配网中已经有了)，新增常用亮度设置（自动亮度关闭时），最低亮度设置（自动亮度打开时），英语单词本轮播时间设置(分钟)
//断电情况下，按下按钮不松开，然后插上TYPE-C数据线通电，上电后大概等待1秒，屏幕上会有提示，提示停留在哪一个步骤，松开按钮就会进入该步骤，重启后生效
//按键控制功能有：
//1,自动亮度打开与关闭
//2,配网模式
//3,开机动画关闭
//4,开机动画设置为图片1（默认）
//5,开机动画设置为图片2
//6,开机动画设置为图片3
//7,底部动画设置为图片1（默认）
//8,底部动画设置为图片2
//9,闹钟打开与关闭
//10,页面选择1天气时钟（默认）
//11,页面选择2全屏数字时钟
//12,页面选择3圆盘时钟
//13,页面选择4投屏助手
//14,页面选择5英语单词本
//15,页面选择6喝水小助手
//16,页面选择7游戏flappy bird
//17,页面选择8系统信息
//18,页面选择9关于
//增加全屏数字时钟界面，按下按键可立即同步ntp时间
//增加圆盘时钟界面，按下按键可立即同步ntp时间
//增加投屏功能页面，需上位机配合
//增加英语单词本功能，支持轮播时间设置，按下按键可立即换单词和同步ntp时间,默认7990个单词。
//增加喝水小助手功能，默认8杯水，按一次增加一次，提示不同内容和显示进度，掉电不丢失，每天夜间1点10分清0重新计数。超过24次后，重启会清零。
//增加游戏flappy bird，按键操作，最高分保存记录掉电不丢失

//我的更改说明：V1.1程序
//1,增加了闹钟,在配网里面，配网完成后需要上电前按下按键选择闹钟打开模式才能使用,默认响1分钟,响铃的时候长按按键可关闭。


//我的更改说明：V1.2程序
//1,源码无变化,更新了烧录方式，不再使用麻烦的arduino手动分区，实现一键烧写。

//新增库，arduino设置正确的开发板，否则可能找不到这个Preferences.h文件。
#include <Preferences.h>
Preferences preferences; 

//新增字符串，存储wifi用户名和密码
String PrefSSID, PrefPassword; 





//ArduinoJson用V6版本，用于url解析
#include "ArduinoJson.h"

#include <TimeLib.h>
#include  <WiFi.h>
#include <HTTPClient.h>
#include <WiFiUdp.h>
#include <TFT_eSPI.h> 
#include <SPI.h>
#include <TJpg_Decoder.h>
#include <EEPROM.h>

#include "number.h"
#include "weathernum.h"


//字体文件
#include "font/bili.h"
#include "font/ZdyLwFont_20.h"
#include "font/zkyyt48.h"
#include "font/zkyyt72.h"
//图片类文件

#include "img/temperature.h"
#include "img/humidity.h"
#include "img/pangzi/i0.h"
#include "img/pangzi/i1.h"
#include "img/pangzi/i2.h"
#include "img/pangzi/i3.h"
#include "img/pangzi/i4.h"
#include "img/pangzi/i5.h"
#include "img/pangzi/i6.h"
#include "img/pangzi/i7.h"
#include "img/pangzi/i8.h"
#include "img/pangzi/i9.h"

//新增图片
//开机动画
#include "img\startlogo\chuyin1.h"
#include "img\startlogo\chuyin2.h"
#include "img\startlogo\chuyin3.h"

//底部动画
#include "img\dbgif\db1.h"
#include "img\dbgif\db2.h"
//重启动画
#include "img\reboot.h"
//杯子图片
#include "img\bzpic.h"
//喝水进度图
#include "img\waterjd.h"

//flappy bird图案
#include "img/bird01.h"

//Web配网
#include "src/SetWiFi.h"
#include "img/setWiFi_img.h"

//b站图标
#include "img/bilispace.h"

//英语单词本
#include "Englishlist.h"
#include "Englishfy.h"

//定义背光控制引脚
#define LCD_BL_PIN 22
//定义光敏电阻输入引脚
#define GL5528  32
//定义模式按钮输入引脚
#define Button  4 
//定义蜂鸣器引脚
#define PIN_BUZZER 13
#define BUZZER_FREQ 2500
#define startBeep() ledcWrite(1, 255)
#define stopBeep() ledcWrite(1,0)



//自动亮度控制 true - 打开 false - 关闭
bool AutoBright = true ; 
//自动亮度下，串口调亮度无效，仅在关闭自动亮度控制下有效。
int MiniBright=30;
//闹钟开关,0为关，1为开，默认关
int AlarmFlag=0;


//开机动画,0为关,1为图片1,以此类推,默认1
int startlogo=1;

//页面选择，默认1，不同数字调用不同页面功能
int pagenum=1;

//底部动画,1为图片1,以此类推,默认1
int dbgif=1;

//底部中间变量
int tdbgif=1;

//自动亮度控制中间变量,0为关，1为开
int brightc=1;
//闹钟控制中间变量,0为关，1为开
int alarmc=0;
//开机动画中间变量
int slogo=1;
//最低亮度中间变量
int mbright=-1;

//页面临时变量存储
int tpagenum=1;


//夜间时刻
int backLight_hour=0;



//屏幕初始化放在最前，以免写函数调用clk找不到


TFT_eSPI tft = TFT_eSPI();  // 引脚请自行配置tft_espi库中的 User_Setup.h文件
TFT_eSprite clk = TFT_eSprite(&tft);





//-------------------------------------------关于界面


void showgy()
{

    clk.loadFont(ZdyLwFont_20);
    clk.createSprite(240,22); 
    clk.fillSprite(0x0000); 
    clk.setTextDatum(CC_DATUM);
    clk.setTextColor(TFT_WHITE, 0x0000);
    clk.drawString("关于",120,11);
    clk.pushSprite(0,0);
    clk.deleteSprite();
    clk.unloadFont(); //释放加载字体资源


    clk.loadFont(ZdyLwFont_20);
    clk.createSprite(240,22); 
    clk.fillSprite(0x0000); 
    clk.setTextDatum(ML_DATUM);
    clk.setTextColor(TFT_WHITE, 0x0000);
    clk.drawString("程序版本:appcard V1.2",1,11);
    clk.pushSprite(0,24);
    clk.deleteSprite();
    clk.unloadFont(); //释放加载字体资源
    

    clk.loadFont(ZdyLwFont_20);
    clk.createSprite(240,22); 
    clk.fillSprite(0x0000); 
    clk.setTextDatum(ML_DATUM);
    clk.setTextColor(TFT_WHITE, 0x0000);
    clk.drawString("制作者:B站-明明很萌的 ",1,11);
    clk.pushSprite(0,48);
    clk.deleteSprite();
    clk.unloadFont(); //释放加载字体资源


   clk.setColorDepth(8);
   TJpgDec.setJpgScale(1);
   TJpgDec.setSwapBytes(true);
   TJpgDec.drawJpg(60,80,bilispace, sizeof(bilispace)); 

    
  
}



//-----------------------------------------系统信息页面

uint64_t chipid; 

void showespsys()
{  
  chipid=ESP.getEfuseMac();
   
    clk.loadFont(ZdyLwFont_20);
    clk.createSprite(240,22); 
    clk.fillSprite(0x0000); 
    clk.setTextDatum(CC_DATUM);
    clk.setTextColor(TFT_WHITE, 0x0000);
    clk.drawString("系统信息",120,11);
    clk.pushSprite(0,0);
    clk.deleteSprite();
    clk.unloadFont(); //释放加载字体资源


    clk.loadFont(ZdyLwFont_20);
    clk.createSprite(240,22); 
    clk.fillSprite(0x0000); 
    clk.setTextDatum(ML_DATUM);
    clk.setTextColor(TFT_WHITE, 0x0000);
    clk.drawString("工作模式:"+String(ESP.getFlashChipMode()),1,11);
    clk.pushSprite(0,24);
    clk.deleteSprite();
    clk.unloadFont(); //释放加载字体资源
    
    clk.loadFont(ZdyLwFont_20);
    clk.createSprite(240,22); 
    clk.fillSprite(0x0000); 
    clk.setTextDatum(ML_DATUM);
    clk.setTextColor(TFT_WHITE, 0x0000);
    clk.drawString("芯片类型:ESP32 WROVER ",1,11);
    clk.pushSprite(0,48);
    clk.deleteSprite();
    clk.unloadFont(); //释放加载字体资源

    clk.loadFont(ZdyLwFont_20);
    clk.createSprite(240,22); 
    clk.fillSprite(0x0000); 
    clk.setTextDatum(ML_DATUM);
    clk.setTextColor(TFT_WHITE, 0x0000);
    clk.drawString("芯片ID:"+String((uint16_t)(chipid>>32))+String((uint32_t)chipid),1,11);
    clk.pushSprite(0,72);
    clk.deleteSprite();
    clk.unloadFont(); //释放加载字体资源

    clk.loadFont(ZdyLwFont_20);
    clk.createSprite(240,22); 
    clk.fillSprite(0x0000); 
    clk.setTextDatum(ML_DATUM);
    clk.setTextColor(TFT_WHITE, 0x0000);
    clk.drawString("总内存:"+String(ESP.getHeapSize()),1,11);
    clk.pushSprite(0,96);
    clk.deleteSprite();
    clk.unloadFont(); //释放加载字体资源

    clk.loadFont(ZdyLwFont_20);
    clk.createSprite(240,22); 
    clk.fillSprite(0x0000); 
    clk.setTextDatum(ML_DATUM);
    clk.setTextColor(TFT_WHITE, 0x0000);
    clk.drawString("剩余内存:"+String(ESP.getFreeHeap()),1,11);
    clk.pushSprite(0,120);
    clk.deleteSprite();
    clk.unloadFont(); //释放加载字体资源


    clk.loadFont(ZdyLwFont_20);
    clk.createSprite(240,22); 
    clk.fillSprite(0x0000); 
    clk.setTextDatum(ML_DATUM);
    clk.setTextColor(TFT_WHITE, 0x0000);
    clk.drawString("Psram总内存:"+String(ESP.getPsramSize()),1,11);
    clk.pushSprite(0,146);
    clk.deleteSprite();
    clk.unloadFont(); //释放加载字体资源


    clk.loadFont(ZdyLwFont_20);
    clk.createSprite(240,22); 
    clk.fillSprite(0x0000); 
    clk.setTextDatum(ML_DATUM);
    clk.setTextColor(TFT_WHITE, 0x0000);
    clk.drawString("Psram可用:"+String(ESP.getFreePsram()),1,11);
    clk.pushSprite(0,170);
    clk.deleteSprite();
    clk.unloadFont(); //释放加载字体资源

    clk.loadFont(ZdyLwFont_20);
    clk.createSprite(240,22); 
    clk.fillSprite(0x0000); 
    clk.setTextDatum(ML_DATUM);
    clk.setTextColor(TFT_WHITE, 0x0000);
    clk.drawString("芯片版本号:"+String(ESP.getChipRevision()),1,11);
    clk.pushSprite(0,195);
    clk.deleteSprite();
    clk.unloadFont(); //释放加载字体资源


    clk.loadFont(ZdyLwFont_20);
    clk.createSprite(240,22); 
    clk.fillSprite(0x0000); 
    clk.setTextDatum(ML_DATUM);
    clk.setTextColor(TFT_WHITE, 0x0000);
    clk.drawString("芯片频率:"+String(ESP.getCpuFreqMHz()),1,11);
    clk.pushSprite(0,220);
    clk.deleteSprite();
    clk.unloadFont(); //释放加载字体资源


    clk.loadFont(ZdyLwFont_20);
    clk.createSprite(240,22); 
    clk.fillSprite(0x0000); 
    clk.setTextDatum(ML_DATUM);
    clk.setTextColor(TFT_WHITE, 0x0000);
    clk.drawString("芯片速度:"+String(ESP.getFlashChipSpeed()),1,11);
    clk.pushSprite(0,240);
    clk.deleteSprite();
    clk.unloadFont(); //释放加载字体资源


    clk.loadFont(ZdyLwFont_20);
    clk.createSprite(240,22); 
    clk.fillSprite(0x0000); 
    clk.setTextDatum(ML_DATUM);
    clk.setTextColor(TFT_WHITE, 0x0000);
    clk.drawString("SDK版本:"+String(ESP.getSdkVersion()),1,11);
    clk.pushSprite(0,265);
    clk.deleteSprite();
    clk.unloadFont(); //释放加载字体资源

    clk.loadFont(ZdyLwFont_20);
    clk.createSprite(240,22); 
    clk.fillSprite(0x0000); 
    clk.setTextDatum(ML_DATUM);
    clk.setTextColor(TFT_WHITE, 0x0000);
    clk.drawString("SDK版本:"+String(ESP.getSdkVersion()),1,11);
    clk.pushSprite(0,265);
    clk.deleteSprite();
    clk.unloadFont(); //释放加载字体资源


    clk.loadFont(ZdyLwFont_20);
    clk.createSprite(240,22); 
    clk.fillSprite(0x0000); 
    clk.setTextDatum(ML_DATUM);
    clk.setTextColor(TFT_WHITE, 0x0000);
    clk.drawString("程序容量:"+String(ESP.getSketchSize()),1,11);
    clk.pushSprite(0,290);
    clk.deleteSprite();
    clk.unloadFont(); //释放加载字体资源



  
}


















//-------------------------------------------flappy bird 游戏代码区

//extern uint8_t SmallFont[];
//extern uint8_t BigFont[];
//extern uint8_t SevenSegNumFont[];

//extern unsigned int bird01[0x41A]; // Bird Bitmap

//int x, y; // Variables for the coordinates where the display has been pressed

// Floppy Bird
int xP = 319;//柱子宽度
int yP = 100;//柱子高度
int yB = 50; //鸟Y坐标
int movingRate = 3;
int fallRateInt = 0;
float fallRate = 0;
int score = 0;
int lastSpeedUpScore = 0;
int highestScore;
boolean screenPressed = false;
boolean gameStarted = false;


int tmpscore=0;

// ===== initiateGame - Custom Function
void initiateGame(){


   

  //myGLCD.clrScr();
    tft.fillScreen(0x0000);
   // Blue background
  //  myGLCD.setColor(114, 198, 206);
  //  myGLCD.fillRect(0,0,319,239);


  tft.fillRect(0, 0, 320, 240, 0x867D);

  // Ground
//  myGLCD.setColor(221,216,148);
//  myGLCD.fillRect(0, 215, 319, 239);
 
  tft.fillRect(0, 215, 320, 25, 0xFFE0);


//  myGLCD.setColor(47,175,68);
//  myGLCD.fillRect(0, 205, 319, 214);

   tft.fillRect(0, 205, 320,10,0xB7E0);




  // Text
//  myGLCD.setColor(0, 0, 0);
//  myGLCD.setBackColor(221, 216, 148);
//  myGLCD.setFont(BigFont);
//  myGLCD.print("Score:",5,220);
//  myGLCD.setFont(SmallFont);
//  myGLCD.print("HowToMechatronics.com", 140, 220); 
//  myGLCD.setColor(0, 0, 0);
//  myGLCD.setBackColor(114, 198, 206);
//  myGLCD.print("Highest Score: ",5,5);
//  myGLCD.printNumI(highestScore, 120, 6);
//  myGLCD.print(">RESET<",255,5);
//  myGLCD.drawLine(0,23,319,23);
//  myGLCD.print("TAP TO START",CENTER,100);
   
    clk.loadFont(ZdyLwFont_20);
    clk.createSprite(50,22);
    clk.fillSprite(0xFFE0); 
    clk.setTextDatum(ML_DATUM);
    clk.setTextColor(0xF800, 0xFFE0);
    clk.drawString("得分:",1,11);
    clk.pushSprite(0,220);
    clk.deleteSprite();
    clk.unloadFont(); //释放加载字体资源
 
    clk.loadFont(ZdyLwFont_20);
    clk.createSprite(120,22); 
    clk.fillSprite(0x867D); 
    clk.setTextDatum(ML_DATUM);
    clk.setTextColor(0xF81F, 0x867D);
    clk.drawString("最高分:"+String(highestScore),1,11);
    clk.pushSprite(0,0);
    clk.deleteSprite();
    clk.unloadFont(); //释放加载字体资源

    clk.loadFont(ZdyLwFont_20);
    clk.createSprite(120,22); 
    clk.fillSprite(0x867D); 
    clk.setTextDatum(ML_DATUM);
    clk.setTextColor(0xFDA0, 0x867D);
    clk.drawString("Flappy  Bird",1,11);
    clk.pushSprite(100,120);
    clk.deleteSprite();
    clk.unloadFont(); //释放加载字体资源

     
     drawBird(yB); // Draws the bird
  
  // Wait until we tap the sreen
//  while (!gameStarted) {
//    if (myTouch.dataAvailable()) {
//    myTouch.read();
//    x=myTouch.getX();
//    y=myTouch.getY();        
//    // Reset higest score
//    if ((x>=250) && (x<=319) &&(y>=0) && (y<=28)) {
//    highestScore = 0;
//    myGLCD.setColor(114, 198, 206);
//   myGLCD.fillRect(120, 0, 150, 22);
//    myGLCD.setColor(0, 0, 0);
//    myGLCD.printNumI(highestScore, 120, 5);
//    } 

//    if ((x>=0) && (x<=319) &&(y>=30) && (y<=239)) {
//    gameStarted = true;
//    myGLCD.setColor(114, 198, 206);
//    myGLCD.fillRect(0, 0, 319, 32);
//    }   
//  }
//  }
  // Clears the text "TAP TO START" before the game start
//  myGLCD.setColor(114, 198, 206)
//  myGLCD.fillRect(85, 100, 235, 116);

    //重置分数功能和提示内容去除暂时不需要

     while (!gameStarted)
    {  
      
       if(digitalRead(Button) == HIGH)
       {
        
          delay(10);//需要延时防抖动
          gameStarted = true;

   
          tft.fillRect(0,0,120,22,0x867D);//游戏中屏蔽最高分记录
          tft.fillRect(100,120,120,22,0x867D);//游戏中屏蔽游戏标题
 
         
        
       }

      
    }
    
    
}
// ===== drawPlillars - Custom Function


//重绘图形消除残影函数
//x1,y1,x2,y2，uint16_t bgcolor
//定义翻转函数

void fzfillRect(int x1,int y1,int x2,int y2,uint16_t fillcolor)
{
     if (x1>x2)
  {
    int tempdd1=x1;
    x1=x2;
    x2=tempdd1;
    
  }
  if (y1>y2)
  {
    int tempdd2=y1;
    y1=y2;
    y2=tempdd2;
  }
            
      tft.fillRect(x1,y1,abs(x2-x1)+1,abs(y2-y1)+1,fillcolor);
}

void fzdrawRect(int x1,int y1,int x2,int y2,uint16_t drawcolor)
{

      if (x1>x2)
  {
    int tempdd1=x1;
    x1=x2;
    x2=tempdd1;
    
  }
  if (y1>y2)
  {
    int tempdd2=y1;
    y1=y2;
    y2=tempdd2;
  }
            
            
   tft.drawRect(x1,y1,abs(x2-x1)+1,abs(y2-y1)+1,drawcolor);

}




void drawPilars(int x, int y) {

   
    if (x>=270){

//      myGLCD.setColor(0, 200, 20);
//       myGLCD.fillRect(318, 0, x, y-1);
//       myGLCD.setColor(0, 0, 0);
//       myGLCD.drawRect(319, 0, x-1, y);



fzfillRect(318,0,x,y-1,0x07E0);
fzdrawRect(319,0,x-1,y,0x0000);

//       myGLCD.setColor(0, 200, 20);
//       myGLCD.fillRect(318, y+81, x, 203);
//       myGLCD.setColor(0, 0, 0);
//       myGLCD.drawRect(319, y+80, x-1, 204); 
 
fzfillRect(318,y+81,x,203,0x07E0);
fzdrawRect(319,y+80,x-1,204,0x0000);
 
    }
    else if( x<=268) {
       
      // Draws blue rectangle right of the pillar
//       myGLCD.setColor(114, 198, 206);
//       myGLCD.fillRect(x+51, 0, x+60, y);


  fzfillRect(x+51,0,x+60,y,0x867D);

      // Draws the pillar
//       myGLCD.setColor(0, 200, 20);
//       myGLCD.fillRect(x+49, 1, x+1, y-1);

 fzfillRect(x+49,1,x+1,y-1,0x07E0);

      // Draws the black frame of the pillar
//       myGLCD.setColor(0, 0, 0);
//       myGLCD.drawRect(x+50, 0, x, y);


 fzdrawRect(x+50,0,x,y,0x0000);


      // Draws the blue rectangle left of the pillar
//       myGLCD.setColor(114, 198, 206);
//       myGLCD.fillRect(x-1, 0, x-3, y);


 fzfillRect(x-1,0,x-3,y,0x867D);

      // The bottom pillar
//       myGLCD.setColor(114, 198, 206);
//       myGLCD.fillRect(x+51, y+80, x+60, 204);


  fzfillRect(x+51,y+80,x+60,204,0x867D);
 
//       myGLCD.setColor(0, 200, 20);
//       myGLCD.fillRect(x+49, y+81, x+1, 203);


  
    fzfillRect(x+49,y+81,x+1,203,0x07E0);



//       myGLCD.setColor(0, 0, 0);
//       myGLCD.drawRect(x+50,y+80,x, 204);
  
   
   

   fzdrawRect(x+50,y+80,x,204,0x0000);
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
void loop()
{
  if(pagenum==1)

  {
           if (now() != prevDisplay) {
            prevDisplay = now();
            digitalClockDisplay();
            prevTime=0;  
          }
          
          if(millis() - weaterTime > 300000){ //5分钟更新一次天气
            weaterTime = millis();
            getCityWeater();
            get_Bstation_follow();
            fanspush();
          }
          scrollBanner();
          imgAnim();
          bilishow();

           if(digitalRead(Button) == HIGH)
          {
            delay(500);
            get_Bstation_follow();
            fanspush();
            delay(500);
            getNtpTime();

          }
  }


   if(pagenum==2)

  {
           if (now() != prevDisplay) {
            prevDisplay = now();
            FClock();
            prevTime=0;  
          }

           if(digitalRead(Button) == HIGH)
          {
            delay(500);
            getNtpTime();
          }
          
  }


  if(pagenum==3)

  {
             if (targetTimey < millis()) {
              targetTimey += 1000;
              ss++;              // Advance second
              if (ss==60) {
                ss=0;
                mm++;            // Advance minute
                if(mm>59) {
                  mm=0;
                  hh++;          // Advance hour
                  if (hh>23) {
                    hh=0;
                  }
                }
              }
          
              // Pre-compute hand degrees, x & y coords for a fast screen update
              sdeg = ss*6;                  // 0-59 -> 0-354
              mdeg = mm*6+sdeg*0.01666667;  // 0-59 -> 0-360 - includes seconds
              hdeg = hh*30+mdeg*0.0833333;  // 0-11 -> 0-360 - includes minutes and seconds
              hx = cos((hdeg-90)*0.0174532925);    
              hy = sin((hdeg-90)*0.0174532925);
              mx = cos((mdeg-90)*0.0174532925);    
              my = sin((mdeg-90)*0.0174532925);
              sx = cos((sdeg-90)*0.0174532925);    
              sy = sin((sdeg-90)*0.0174532925);
          
              if (ss==0 || initial) {
                initial = 0;
                // Erase hour and minute hand positions every minute
                tft.drawLine(ohx, ohy, 120, 121, TFT_BLACK);
                ohx = hx*62+121;    
                ohy = hy*62+121;
                tft.drawLine(omx, omy, 120, 121, TFT_BLACK);
                omx = mx*84+120;    
                omy = my*84+121;
              }
          
                // Redraw new hand positions, hour and minute hands not erased here to avoid flicker
                tft.drawLine(osx, osy, 120, 121, TFT_BLACK);
                osx = sx*90+121;    
                osy = sy*90+121;
                tft.drawLine(osx, osy, 120, 121, TFT_RED);
                tft.drawLine(ohx, ohy, 120, 121, TFT_WHITE);
                tft.drawLine(omx, omy, 120, 121, TFT_WHITE);
                tft.drawLine(osx, osy, 120, 121, TFT_RED);
          
              tft.fillCircle(120, 121, 3, TFT_RED);
            }

          if(digitalRead(Button) == HIGH)
          {
            delay(500);
            getNtpTime();
          }
          

      
          
  }

   if(pagenum==4)

  {
             // put your main code here, to run repeatedly:
            //沾包问题 recv阻塞，长时间收不到数据就会断开
            //断开连接原因，读取buff太快，上位机发送太快造成buff溢出，清空缓冲区会断开（FLUSH）
            WiFiClient clienttpzs = servertpzs.available(); //尝试建立客户对象
            if(clienttpzs){
              Serial.println("[New Client!]");
              clienttpzs.write("ok");//向上位机发送下一帧发送指令
              
              while(clienttpzs.connected())//如果客户端处于连接状态client.connected()
              {
                clienttpzs.write("no");//向上位机发送当前帧未写入完指令
                while(clienttpzs.available()){
                  while (clienttpzs.available()) {//检测缓冲区是否有数据
                       if(read_count==0)
                        {
                          start_time=millis();
                          clienttpzs.read(pack_size,2);//读取帧大小
                          frame_size=pack_size[0]+(pack_size[1]<<8);
                       }
                       read_count=clienttpzs.read(buff,7000);//向缓冲区读取数据
                       memcpy(&img_buff[size_count],buff,read_count);//将读取的buff字节地址复制给img_buff数组
                       size_count=size_count+read_count;//计数当前帧字节位置
            //           Serial.println(size_count);
                       if(img_buff[frame_size-3]==0xaa && img_buff[frame_size-2]==0xbb && img_buff[frame_size-1]==0xcc)//判断末尾数据是否当前帧校验位
                       {
                        receive_time=millis()-start_time;
                        deal_time=millis();
                        img_buff[frame_size-3]=0;img_buff[frame_size-2]=0;img_buff[frame_size-1]=0;//清除标志位
                        tft.startWrite();//必须先使用startWrite，以便TFT芯片选择保持低的DMA和SPI通道设置保持配置
                        TJpgDec.drawJpg(0,0,img_buff, sizeof(img_buff));//在左上角的0,0处绘制图像——在这个草图中，DMA请求在回调tft_output()中处理
                        tft.endWrite();//必须使用endWrite来释放TFT芯片选择和释放SPI通道吗
            //            memset(&img_buff,0,sizeof(img_buff));//清空buff
                        size_count=0;//下一帧
                        read_count=0;
                        clienttpzs.write("ok");//向上位机发送下一帧发送指令
                        end_time = millis(); //计算mcu刷新一张图片的时间，从而算出1s能刷新多少张图，即得出最大刷新率
                        Serial.printf("帧大小：%d " ,frame_size);Serial.print("MCU处理速度："); Serial.print(1000 / (end_time - start_time), 2); Serial.print("Fps");
                        Serial.printf("帧接收耗时:%.2fms,帧解码显示耗时:%.2fms\n",receive_time,(millis()-deal_time));
                        break;
                        }       
                  }
                }
              }
              clienttpzs.stop();
              Serial.println("连接中断,请复位重新创建服务端");
            }
  }

       if(pagenum==5)

   {
     
           if (now() != prevDisplay)
            {
            prevDisplay = now();
            smallClock();
            prevTime=0;  
            }        

           if(millis() - weaterTime > Truefreshtime){ //默认1分钟更新一次单词本
           weaterTime = millis();
           showEnglish();
          }

          if(digitalRead(Button) == HIGH)
          {  
             delay(500);
             showEnglish();
             delay(500);
             getNtpTime();
          }
         
   }


         if(pagenum==6)

   {
           clearwaternum();
           if (now() != prevDisplay)
            {
            prevDisplay = now();
            smallClock();
            prevTime=0;  
            }        
            
          
          if(digitalRead(Button) == HIGH)
          {  
             delay(500);
             waternum=waternum+1;
             EEPROM.write(61,waternum);
             EEPROM.commit(); 
             watershow();           
             getNtpTime();
          }
         
   }



          if(pagenum==7)
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
